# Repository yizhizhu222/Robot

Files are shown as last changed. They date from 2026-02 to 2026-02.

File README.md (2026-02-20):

# Vision-Rover: 基于 YOLOv8 的端侧视觉追踪机器人

> **“看见目标，精准出击”**
> 本项目是一个端到端的视觉追踪智能车解决方案。采用“上位机视觉+下位机控制”的标准机器人架构，结合轻量化 NCNN 框架与 FreeRTOS 实时系统，实现高帧率的目标检测与丝滑的差速底盘追踪。

---

## 免责声明 (Disclaimer)

**本项目为个人学习与极客折腾产物，核心目的是验证 YOLOv8 在 Orange Pi 端侧的部署可行性，以及 STM32 的底盘闭环控制逻辑。**

代码及硬件方案按“原样 (As-Is)”开源提供。由于嵌入式环境、硬件批次差异以及 Linux 权限的复杂性，本人不保证代码在任何第三方硬件上均能开箱即用，亦不提供环境配置的免费技术支持。

遇到报错的同学请自行发挥极客精神，善用搜索引擎与 AI 排查问题（提示：多留意串口权限与绝对路径）。祝折腾愉快！🍀

---

## 项目亮点
* **灵活定制**：支持在 Windows 端自定义训练 YOLOv8 模型，想追踪什么（人、小球、特定车辆）由你自己训练。
* **端侧极速推理**：利用 ncnn 框架在 Orange Pi Zero 3 上实现轻量化部署，榨干 ARM CPU 性能。
* **工业级底盘控制**：STM32F103C8T6 运行 FreeRTOS，结合双路编码器与 PID 闭环，实现精准的差速运动学调度。

---

## 硬件采购清单 (BOM)

如果你想从零复现本项目，需要准备以下核心硬件：

| 硬件分类 | 推荐型号/规格 | 作用说明 |
| :--- | :--- | :--- |
| **视觉大脑** | Orange Pi Zero 3 (香橙派) | 运行 Linux 系统与 NCNN 视觉推理算法 |
| **底盘小脑** | STM32F103C8T6 核心板 | 运行 FreeRTOS 实时控制电机与读取传感器 |
| **底盘结构** | 可参考项目内 PCB 扩展板 + 亚克力/金属车模 | 承载硬件与电路连接 |
| **执行机构** | 带有 AB 相霍尔编码器的直流减速电机 | 提供动力及速度反馈 |
| **视觉输入** | 普通 USB 摄像头 (免驱) | 采集环境图像 |
| **电源模块** | 12V 动力锂电池 + 5V 降压模块 (Buck) | 分别为电机和逻辑控制板供电 |
| **其他零配件** | JGB32-520 电机 *2 或 *4<br>85mm 实心轮胎 *2<br>BB 响 (用于航模电池测电)<br>双面胶 (实现 MVP 快速组装)<br>Type-C 数据线<br>T插公母头 (如使用航模电池)<br>TB6612 电机驱动模块<br>LM2596S DC 降压模块 | 组装必需的周边耗材与驱动件 |

---

## 硬件架构与供电接线 (Hardware & Wiring)

本项目的硬件供电逻辑经过专门设计，实现了大电流电机与精密逻辑主板的物理隔离供电，防止电压突变导致死机。

### 核心接线逻辑
1. **动力系统**：电池直接接入 PCB 底板，为 STM32 及电机驱动芯片提供原生大电流。
2. **逻辑降压**：电池通过红黑裸线接入降压模块，将电压降至稳定的 5V。
3. **视觉供电**：降压模块通过 Type-C 线连接 Orange Pi Zero 3，为其独立供电。
4. **通信连线**：Orange Pi 的 TX/RX 通过杜邦线连接至 PCB 对应的 RX/TX（波特率 `115200`）。

> **注：** 电机、编码器的具体连线以及 STM32 的详细引脚分配，请直接参考仓库中的 `PCB原理图` 与 `firmware/*.ioc` 工程配置文件。

---

## 软件架构与部署 (Software Architecture)

### 1. Windows PC 端：模型训练与转换
本项目不局限于特定目标，你可以自由训练模型：
1. 在 Windows 电脑上使用 PyTorch 训练自己的 YOLOv8 模型，导出 `.onnx`。
2. 使用 `onnx2ncnn` 工具，将模型转换为适用于端侧的 `.param`（网络结构）和 `.bin`（权重数据）文件。
3. 将生成的文件拷贝至香橙派的 `vision/model/` 目录下即可。

### 2. Orange Pi 端：视觉推理 (`vision/`)
负责捕捉图像并计算偏差下发指令。

```bash
# 1. 克隆项目 (直接在香橙派终端运行)
git clone [https://github.com/yizhizhu222/Robot.git](https://github.com/yizhizhu222/Robot.git)
cd Robot/vision

# 2. 编译视觉程序
mkdir build && cd build
cmake ..
make -j4

# 3. 运行追踪程序
./robot_eye

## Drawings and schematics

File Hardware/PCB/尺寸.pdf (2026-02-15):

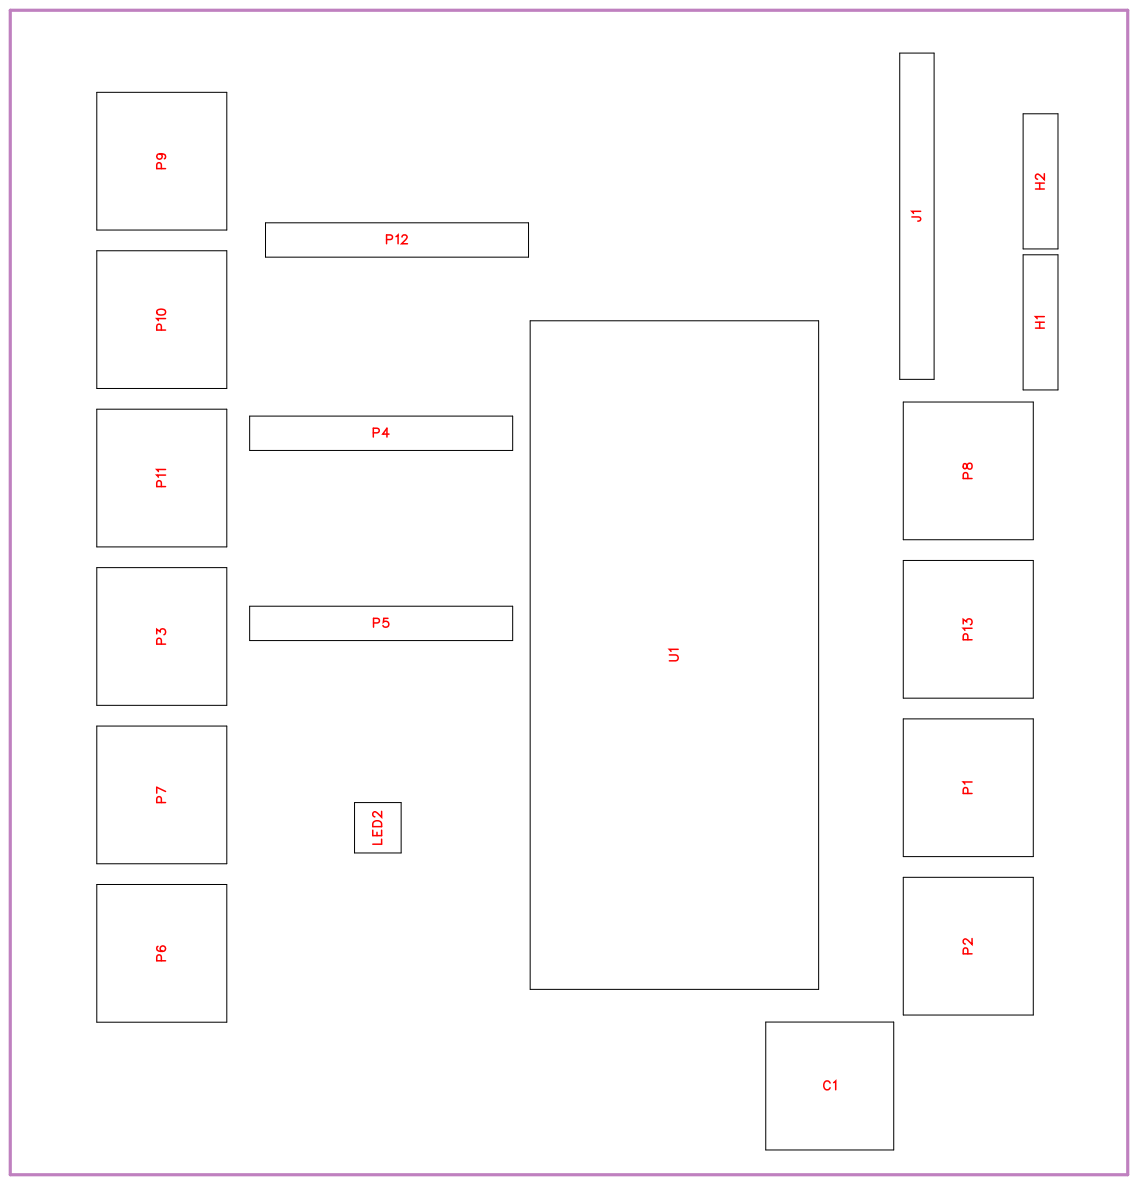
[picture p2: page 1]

No. | Quantity | Comment | Designator | Footprint | Value | Manufacturer Part | Manufacturer | Supplier Part | Supplier
1 | 1 | 470uF | C1 | CAP-TH_BD 10.0-P5.00-D 0.6-FD | 470uF | ERG35V470 M10X13 | JIERR(捷而 瑞) | C47344180 | LCSC
2 | 1 | 香橙派供电和 信息传输 | H1 | HDR-TH_4P-P2.54-V-F | | 香橙派供电和 信息传输 | BOOMELE( ) 博穆精密 | C2718488 | LCSC
3 | 1 | OLED 屏 | H2 | HDR-TH_4P-P2.54-V-F | | OLED 屏 | BOOMELE( ) 博穆精密 | C2718488 | LCSC
4 | 1 | 2.54-1*10P 母 | J1 | HDR-TH_10 P-P2.54-V-F | | 2.54-1*10P 母 | BOOMELE( 博穆精密 ) | C35445 | LCSC
5 | 1 | 3A4GUD | LED2 | LED-TH_BD 3.5-P2.54-R D-GREEN | | 3A4GUD | Guiguang lig ht(桂光光电 ) | C52034646 | LCSC
6 | 1 | 电池出口（进 降压模块） | P1 | CONN-TH_2 P-P5.00_WJ 500V-5.08-2 P | | 电池出口（进 降压模块） | KANGNEX( 康奈克斯电气 ) | C8465 | LCSC
7 | 1 | 电池入口 | P2 | CONN-TH_2 P-P5.00_WJ 500V-5.08-2 P | | 电池入口 | KANGNEX( 康奈克斯电气 ) | C8465 | LCSC
8 | 1 | 电机 2编码器 电源 | P3 | CONN-TH_2 P-P5.00_WJ 500V-5.08-2 P | | 电机 2编码器 电源 | KANGNEX( 康奈克斯电气 ) | C8465 | LCSC
9 | 3 | 2.54-1*8P 母 环保 | P4,P5,P12 | HDR-TH_8P-P2.54-V-F_2 | | 2.54-1*8P 母 环保 | BOOMELE( 博穆精密 ) | C27438 | LCSC
10 | 1 | 电机 2编码 | P6 | CONN-TH_2 P-P5.00_WJ 500V-5.08-2 P | | 2编码 电机 | KANGNEX( 康奈克斯电气 ) | C8465 | LCSC
11 | 1 | 电机 2电源 | P7 | CONN-TH_2 P-P5.00_WJ 500V-5.08-2 P | | 电机 2电源 | KANGNEX( 康奈克斯电气 ) | C8465 | LCSC
12 | 1 | 降压模块进口 | P8 | CONN-TH_2 P-P5.00_WJ 500V-5.08-2 P | | 降压模块进口 | KANGNEX( 康奈克斯电气 ) | C8465 | LCSC
13 | 1 | 电机 1编码 | P9 | CONN-TH_2 P-P5.00_WJ 500V-5.08-2 P | | 电机 1编码 | KANGNEX( 康奈克斯电气 ) | C8465 | LCSC
14 | 1 | 电机 1电源 | P10 | CONN-TH_2 P-P5.00_WJ 500V-5.08-2 P | | 电机 1电源 | KANGNEX( 康奈克斯电气 ) | C8465 | LCSC
15 | 1 | 电机 1编码器 电源 | P11 | CONN-TH_2 P-P5.00_WJ 500V-5.08-2 P | | 电机 1编码器 电源 | KANGNEX( 康奈克斯电气 ) | C8465 | LCSC

16 | 1 | 接入香橙派 | P13 | CONN-TH_2 P-P5.00_WJ 500V-5.08-2 P | 接入香橙派 | KANGNEX( 康奈克斯电气 ) | C8465 | LCSC
17 | 1 | LCKFB-DKX-STM32F103 C8T6 | U1 | CONN-TH_L 53.3-W22.9_ STM32F103 C8T6-CARD | LCKFB-DKX-STM32F103 C8T6 | 立创开发板 | C22396880 | LCSC

# GNDVCC

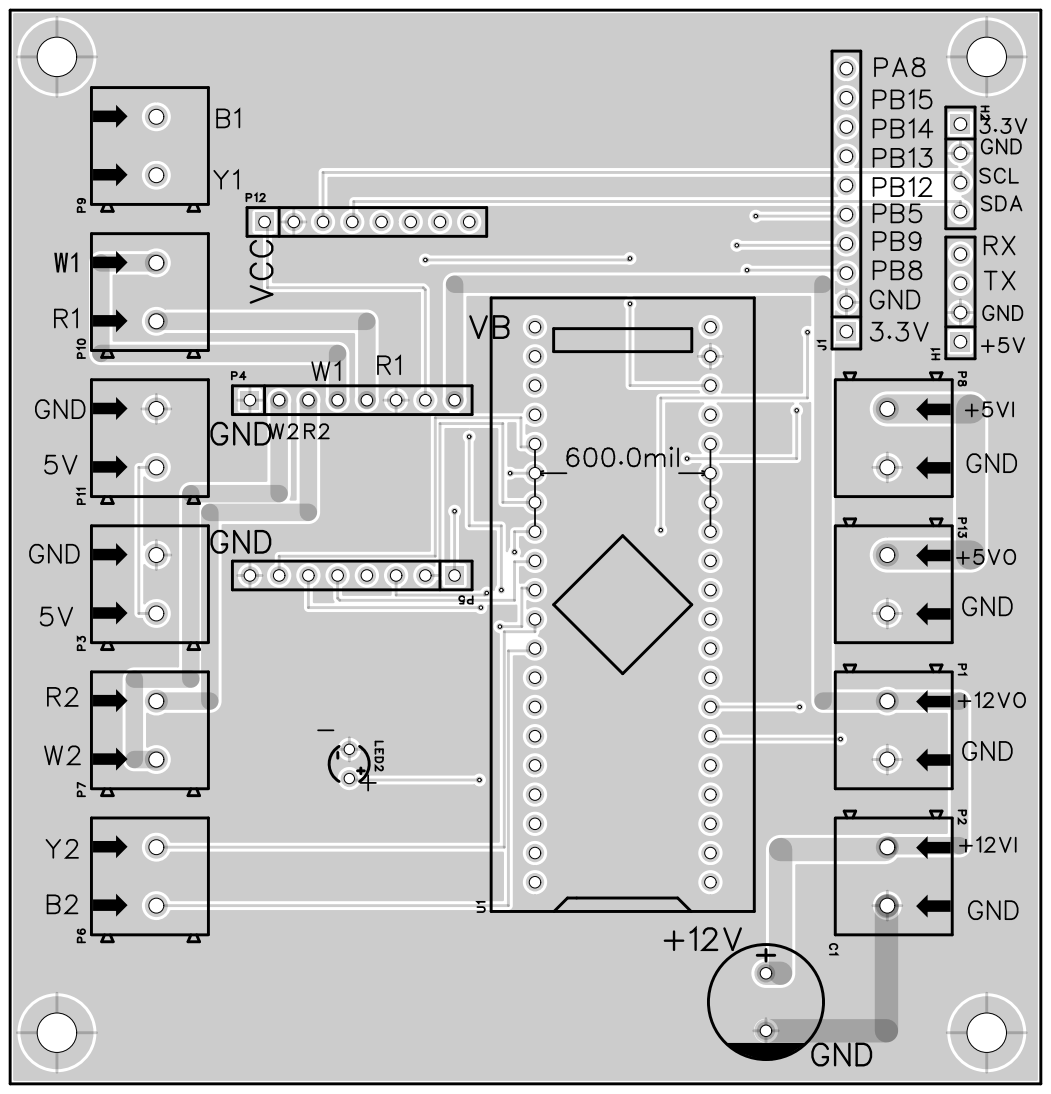
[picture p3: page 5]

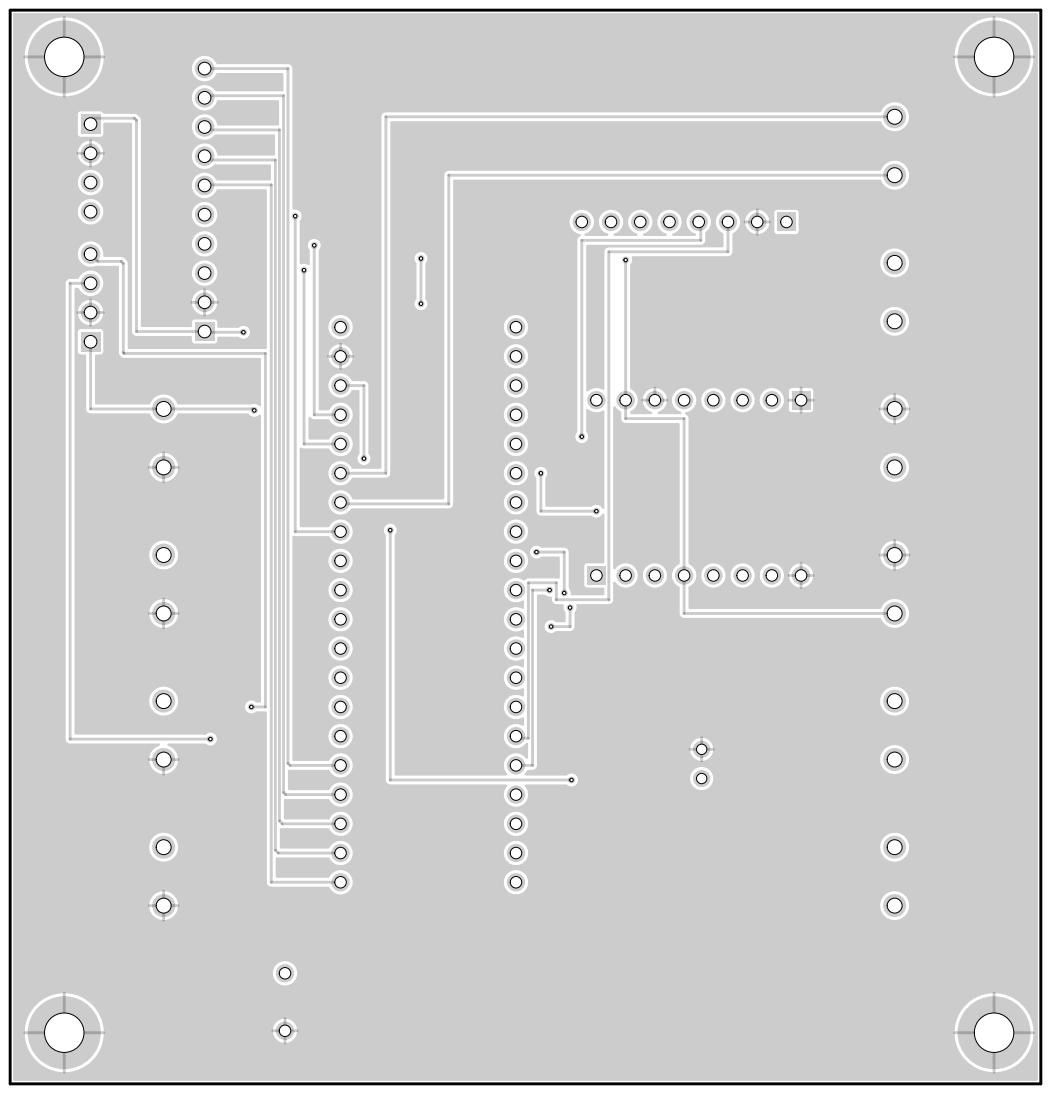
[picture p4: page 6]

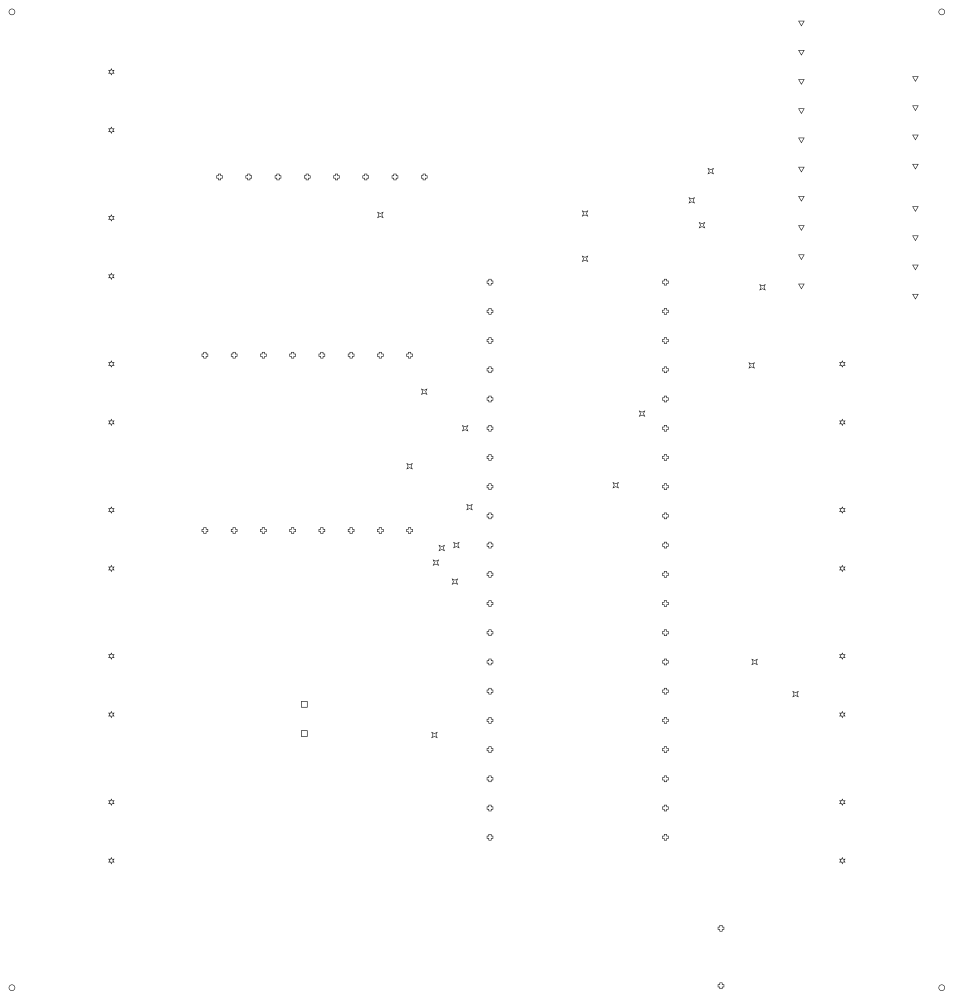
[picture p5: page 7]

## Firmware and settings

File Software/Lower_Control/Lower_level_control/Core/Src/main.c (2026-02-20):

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
/* Includes ------------------------------------------------------------------*/
#include "main.h"
#include "cmsis_os.h"

/* USER CODE BEGIN Includes */
#include <string.h>  // 必须加这个！解决 strstr 警告
#include <stdio.h>
#include <stdlib.h>
#include <protocol.h>
#include <chassis.h>
#include "pid.h"
#include "encoder.h"
#include "motor.h"
#include <math.h>
#include "mpu6050.h"
#include "kinematics.h"
#include "odometry.h"
/* USER CODE END Includes */

/* USER CODE BEGIN PM */
uint8_t rx_data;
/* USER CODE END PM */

I2C_HandleTypeDef hi2c2;

TIM_HandleTypeDef htim2;
TIM_HandleTypeDef htim3;
TIM_HandleTypeDef htim4;

UART_HandleTypeDef huart1;

/* Definitions for Task_Comm */
osThreadId_t Task_CommHandle;
const osThreadAttr_t Task_Comm_attributes = {
  .name = "Task_Comm",
  .stack_size = 256 * 4,
  .priority = (osPriority_t) osPriorityNormal,
};
/* Definitions for Task_Chassis */
osThreadId_t Task_ChassisHandle;
const osThreadAttr_t Task_Chassis_attributes = {
  .name = "Task_Chassis",
  .stack_size = 256 * 4,
  .priority = (osPriority_t) osPriorityHigh,
};
/* Definitions for Task_System */
osThreadId_t Task_SystemHandle;
const osThreadAttr_t Task_System_attributes = {
  .name = "Task_System",
  .stack_size = 256 * 4,
  .priority = (osPriority_t) osPriorityLow,
};
/* USER CODE BEGIN PV */
volatile float User_Target_Linear_X = 0.0f;  // 目标线速度
volatile float User_Target_Angular_Z = 0.0f; // 目标角速度

PID_TypeDef PID_MotorL; 
PID_TypeDef PID_MotorR;
/* USER CODE END PV */

void SystemClock_Config(void);
static void MX_GPIO_Init(void);
static void MX_TIM2_Init(void);
static void MX_USART1_UART_Init(void);
static void MX_TIM3_Init(void);
static void MX_TIM4_Init(void);
static void MX_I2C2_Init(void);
void Comm_Task_Entry(void *argument);
void Chassis_Task_Entry(void *argument);
void System_Task_Entry(void *argument);

/* USER CODE BEGIN 0 */
#define LED_PORT GPIOC
#define LED_PIN  GPIO_PIN_13 

void On_Receive_Velocity(float x, float z)
{
    HAL_GPIO_TogglePin(LED_PORT, LED_PIN);

    Protocol_Send_Odom(x, z); 
	//Chassis_Set_Velocity(x, z);
	User_Target_Linear_X = x;
    User_Target_Angular_Z = z;

}
/* USER CODE END 0 */

/**
  * @brief  The application entry point.
  * @retval int
  */
int main(void)
{

  /* MCU Configuration--------------------------------------------------------*/

  /* Reset of all peripherals, Initializes the Flash interface and the Systick. */
  HAL_Init();

  /* Configure the system clock */
  SystemClock_Config();

  /* Initialize all configured peripherals */
  MX_GPIO_Init();
  MX_TIM2_Init();
  MX_USART1_UART_Init();
  MX_TIM3_Init();
  MX_TIM4_Init();
  MX_I2C2_Init();
  /* USER CODE BEGIN 2 */
  
  // 启动 TIM2 的 Channel 1
  HAL_TIM_PWM_Start(&htim2, TIM_CHANNEL_1);
  // 开启中断接收，每收到 1 个字节，就进一次中断回调函数
  HAL_UART_Receive_IT(&huart1, &rx_data, 1);
  HAL_TIM_Base_Start_IT(&htim2);
  HAL_TIM_PWM_Start(&htim2, TIM_CHANNEL_1);
  HAL_TIM_PWM_Start(&htim2, TIM_CHANNEL_2);
  // 开启编码器计数
  Encoder_Init(); // 内部开启了 TIM3, TIM4
  // 开启 PWM (TIM2/TIM1)
  Motor_Init(); // 内部调用了 HAL_TIM_PWM_Start(&htim1...)
  // 开启串口接收
  HAL_UART_Receive_IT(&huart1, &rx_data, 1);
  MPU_Init();
  MPU_Calibrate();
  /* USER CODE END 2 */

  /* Init scheduler */
  osKernelInitialize();

  /* USER CODE BEGIN RTOS_MUTEX */
  /* add mutexes, ... */
  /* USER CODE END RTOS_MUTEX */

  /* USER CODE BEGIN RTOS_SEMAPHORES */
  /* add semaphores, ... */
  /* USER CODE END RTOS_SEMAPHORES */

  /* USER CODE BEGIN RTOS_TIMERS */
  /* start timers, add new ones, ... */
  /* USER CODE END RTOS_TIMERS */

  /* USER CODE BEGIN RTOS_QUEUES */
  /* add queues, ... */
  /* USER CODE END RTOS_QUEUES */

  /* Create the thread(s) */
  /* creation of Task_Comm */
  Task_CommHandle = osThreadNew(Comm_Task_Entry, NULL, &Task_Comm_attributes);

  /* creation of Task_Chassis */
  Task_ChassisHandle = osThreadNew(Chassis_Task_Entry, NULL, &Task_Chassis_attributes);

  /* creation of Task_System */
  Task_SystemHandle = osThreadNew(System_Task_Entry, NULL, &Task_System_attributes);

  /* USER CODE BEGIN RTOS_THREADS */
  /* add threads, ... */
  /* USER CODE END RTOS_THREADS */

  /* USER CODE BEGIN RTOS_EVENTS */
  /* add events, ... */
  /* USER CODE END RTOS_EVENTS */

  /* Start scheduler */
  osKernelStart();

  /* We should never get here as control is now taken by the scheduler */

  /* Infinite loop */
  /* USER CODE BEGIN WHILE */
  while (1)
  {
    /* USER CODE END WHILE */

    /* USER CODE BEGIN 3 */
  }
  /* USER CODE END 3 */
}

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
/* USER CODE BEGIN 4 */
// 串口接收中断回调函数
// 串口接收中断回调函数
void HAL_UART_RxCpltCallback(UART_HandleTypeDef *huart)
{
    // 判断是不是 USART1 产生的中断
    if (huart->Instance == USART1)
    {
        // 【核心修改】
        // 不需要等 \n，不需要存数组，直接把这个字节喂给解码器！
        Protocol_Decode(rx_data);

        // 重新开启中断，准备接收下一个字节
        HAL_UART_Receive_IT(&huart1, &rx_data, 1);
    }
}
/* USER CODE END 4 */

/* USER CODE BEGIN Header_Comm_Task_Entry */
/**
  * @brief  Function implementing the Task_Comm thread.
  * @param  argument: Not used
  * @retval None
  */
/* USER CODE END Header_Comm_Task_Entry */
void Comm_Task_Entry(void *argument)
{
  /* USER CODE BEGIN 5 */
	
  /* Infinite loop */
  for(;;)
  {
        osDelay(1);
  }
  /* USER CODE END 5 */
}

/* USER CODE BEGIN Header_Chassis_Task_Entry */
/**
* @brief Function implementing the Task_Chassis thread.
* @param argument: Not used
* @retval None
*/
/* USER CODE END Header_Chassis_Task_Entry */
void Chassis_Task_Entry(void *argument)
{
  /* USER CODE BEGIN Chassis_Task_Entry */
	Odometry_Init();
  Chassis_Init();
  Encoder_Init();
  
  // 保持你刚才测试成功的强力参数！千万别改回去了！
  PID_Init(&PID_MotorL, 80.0f, 0.5f, 0.0f, 7199.0f, 4000.0f);
  PID_Init(&PID_MotorR, 80.0f, 0.5f, 0.0f, 7199.0f, 4000.0f);

  Kinematics_Motor_Speed_t target_speed_mps;
  Kinematics_Motor_Pulse_t target_pulse;
  int min_startup_pwm = 1500; // 保持这个低保值

  for(;;)
  {
    // 1. 获取真实指令
    float test_linear_x = User_Target_Linear_X; 
    float test_angular_z = User_Target_Angular_Z;

    // 2. 解算
    target_speed_mps = Kinematics_Inverse(test_linear_x, test_angular_z);
    target_pulse = Kinematics_SpeedToPulse(target_speed_mps, 0.05f);

    // 3. 反馈与PID
    float current_pulse_L = (float)Read_Encoder_Motor1();
    float current_pulse_R = (float)Read_Encoder_Motor2();
    float pwm_L = PID_Compute(&PID_MotorL, target_pulse.left_ticks, current_pulse_L);
    float pwm_R = PID_Compute(&PID_MotorR, target_pulse.right_ticks, current_pulse_R);

    // 4. 安全停车 (如果目标是0，强制关断)
    if (fabs(test_linear_x) < 0.01f && fabs(test_angular_z) < 0.01f) {
        pwm_L = 0;
        pwm_R = 0;
        PID_MotorL.Sum_Error = 0; // 清积分
        PID_MotorR.Sum_Error = 0;
    }
    else {
        // 5. 起步低保 (只有在目标不为0时才给)
        // 左轮
        if (pwm_L > 0 && pwm_L < min_startup_pwm) pwm_L = min_startup_pwm;
        else if (pwm_L < 0 && pwm_L > -min_startup_pwm) pwm_L = -min_startup_pwm;
        // 右轮
        if (pwm_R > 0 && pwm_R < min_startup_pwm) pwm_R = min_startup_pwm;
        else if (pwm_R < 0 && pwm_R > -min_startup_pwm) pwm_R = -min_startup_pwm;
    }

    // 6. 输出
    Motor1_SetSpeed((int)pwm_L);
    Motor2_SetSpeed((int)pwm_R);

    osDelay(50);
  }
  /* USER CODE END Chassis_Task_Entry */
}

/* USER CODE BEGIN Header_System_Task_Entry */
/**
* @brief Function implementing the Task_System thread.
* @param argument: Not used
* @retval None
*/
/* USER CODE END Header_System_Task_Entry */
void System_Task_Entry(void *argument)
{
  /* USER CODE BEGIN System_Task_Entry */
  /* Infinite loop */
  for(;;)
  {
    osDelay(1);
  }
  /* USER CODE END System_Task_Entry */
}

/**
  * @brief  Period elapsed callback in non blocking mode
  * @note   This function is called  when TIM1 interrupt took place, inside
  * HAL_TIM_IRQHandler(). It makes a direct call to HAL_IncTick() to increment
  * a global variable "uwTick" used as application time base.
  * @param  htim : TIM handle
  * @retval None
  */
void HAL_TIM_PeriodElapsedCallback(TIM_HandleTypeDef *htim)
{
  if (htim->Instance == TIM1)
  {
    HAL_IncTick();
  }
}

/**
  * @brief  This function is executed in case of error occurrence.
  * @retval None
  */
void Error_Handler(void)
{
  /* USER CODE BEGIN Error_Handler_Debug */
  /* User can add his own implementation to report the HAL error return state */
  __disable_irq();
  while (1)
  {
  }
  /* USER CODE END Error_Handler_Debug */
}
#ifdef USE_FULL_ASSERT
/**
  * @brief  Reports the name of the source file and the source line number
  *         where the assert_param error has occurred.
  * @param  file: pointer to the source file name
  * @param  line: assert_param error line source number
  * @retval None
  */
void assert_failed(uint8_t *file, uint32_t line)
{
  /* USER CODE BEGIN 6 */
  /* User can add his own implementation to report the file name and line number,
     ex: printf("Wrong parameters value: file %s on line %d\r\n", file, line) */
  /* USER CODE END 6 */
}
#endif /* USE_FULL_ASSERT */

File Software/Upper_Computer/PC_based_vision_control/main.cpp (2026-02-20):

#include <opencv2/opencv.hpp>
#include <stdio.h>
#include <sys/time.h>
#include <fcntl.h>
#include <unistd.h>
#include <termios.h>
#include <string.h> 
#include "yolo.h"

// ================= 核心参数调优区域 (新手最常改这里) =================
#define CENTER_X        160.0f    // 画面中心点 (320宽度的一半)
#define KP_TURN         0.01f     // 【转向灵敏度】数值越大，转弯越猛
#define MAX_TURN_SPEED  1.0f      // 【转速上限】防止机器人转得太快把自己甩飞
#define FORWARD_SPEED   0.2f      // 【前进速度】单位通常是 m/s
#define CONFIDENCE_MIN  0.45f     // 【置信度门槛】低于这个分数的物体会被忽略

// ================= 串口通信 (下位机协议) =================
/**
 * @brief 打开并配置串口 (与单片机通信)
 */
int open_serial(const char *device) {
    int fd = open(device, O_RDWR | O_NOCTTY | O_NDELAY);
    if (fd == -1) { perror("错误：无法打开串口"); return -1; }
    
    struct termios options;
    tcgetattr(fd, &options);
    cfsetispeed(&options, B115200); // 波特率 115200
    cfsetospeed(&options, B115200);
    options.c_cflag |= (CLOCAL | CREAD); // 忽略控制线，开启读取
    options.c_cflag &= ~PARENB;          // 无校验
    options.c_cflag &= ~CSTOPB;          // 1位停止位
    options.c_cflag &= ~CSIZE;
    options.c_cflag |= CS8;              // 8位数据
    
    // 原始模式 (Raw Mode)，不进行回显和换行处理
    options.c_lflag &= ~(ICANON | ECHO | ECHOE | ISIG); 
    options.c_oflag &= ~OPOST;
    tcsetattr(fd, TCSANOW, &options);
    return fd;
}

// 定义发送给机器人的数据结构
struct Velocity_Payload { 
    float linear_x;  // 线速度 (前后)
    float angular_z; // 角速度 (左右转向)
};

/**
 * @brief 按照通讯协议打包并发送速度指令
 */
void send_velocity_command(int fd, float linear_x, float angular_z) {
    uint8_t tx_buf[32]; 
    int idx = 0;
    Velocity_Payload payload = {linear_x, angular_z};
    uint8_t len = sizeof(payload);

    // 填充协议头
    tx_buf[idx++] = 0xAA; // 帧头 1
    tx_buf[idx++] = 0x55; // 帧头 2
    tx_buf[idx++] = 0x10; // 命令 ID: 设置速度
    tx_buf[idx++] = len;  // 数据长度
    
    // 拷贝速度数据
    memcpy(&tx_buf[idx], &payload, len);
    idx += len;

    // 计算校验和 (防止数据传错)
    uint8_t checksum = 0x10 + len;
    uint8_t *pData = (uint8_t*)&payload;
    for (int i = 0; i < len; i++) checksum += pData[i];
    tx_buf[idx++] = checksum;

    write(fd, tx_buf, idx);
}

// ================= 主循环 (大脑运行逻辑) =================
int main() {
    // 1. 初始化串口
    int serial_fd = open_serial("/dev/ttyAS5");
    if (serial_fd != -1) printf("✅ 串口已连接\n");

    // 2. 初始化摄像头 (设置分辨率为 320x240)
    cv::VideoCapture cap(0);
    cap.set(cv::CAP_PROP_FRAME_WIDTH, 320);
    cap.set(cv::CAP_PROP_FRAME_HEIGHT, 240);
    if (!cap.isOpened()) { printf("❌ 无法打开摄像头\n"); return -1; }

    // 3. 加载 YOLO 模型
    Yolo yolo;
    if (yolo.load("/home/orangepi/my_robot/model/yolov8", 320) != 0) return -1;
    
    cv::Mat frame;
    std::vector<Object> objects;
    
    // --- 状态变量 (用于平滑控制) ---
    int lost_target_counter = 0; // 丢失计数器：防止目标闪烁导致车乱跳
    float last_v = 0.0f;
    float last_w = 0.0f;

    while (true) {
        cap >> frame;
        if (frame.empty()) break;

        objects.clear();
        yolo.detect(frame, objects); // 执行目标检测

        float v_x = 0.0f; // 本帧线速度
        float w_z = 0.0f; // 本帧角速度
        bool valid_target_found = false;

        // 策略 A：如果有看到物体
        if (!objects.empty()) {
            const auto& obj = objects[0]; // 只追踪看到的第一个物体
            
            if (obj.prob > CONFIDENCE_MIN) {
                valid_target_found = true;
                lost_target_counter = 0; // 看到东西了，重置丢失计时

                // --- 计算偏离距离 ---
                float cx = obj.rect.x + obj.rect.width / 2.0f; // 物体中心 X
                float error = cx - CENTER_X; // 物体相对于屏幕中心的偏离量

                // 只有偏离超过 20 像素才转向，防止原地细微抖动 (死区逻辑)
                if (abs(error) < 20.0f) error = 0.0f;

                // --- 比例控制 (P 控制) ---
                // 物体在左 (error<0) -> 需要左转 (w_z 为正)
                // 物体在右 (error>0) -> 需要右转 (w_z 为负)
                w_z = -error * KP_TURN; 

                // 限速保护：不要超过电机最大负荷
                if (w_z > MAX_TURN_SPEED) w_z = MAX_TURN_SPEED;
                if (w_z < -MAX_TURN_SPEED) w_z = -MAX_TURN_SPEED;

                v_x = FORWARD_SPEED; // 看到目标就匀速前进
                
                // 记录状态，用于丢失后的“惯性”维持
                last_v = v_x;
                last_w = w_z;

                printf("🎯 [追踪中] 偏差: %.1f | 转向速度: %.3f\n", error, w_z);
            }
        }

        // 策略 B：如果目标丢了 (防抖处理)
        if (!valid_target_found) {
            lost_target_counter++;
            
            // 如果丢失时间很短 (少于 5 帧，约 0.2 秒)
            // 机器人会按照上一帧的指令继续跑，避免因为检测断开而急刹车
            if (lost_target_counter < 5) {
                v_x = last_v;
                w_z = last_w;
                printf("⚠️ [目标丢失] 维持惯性... (%d/5)\n", lost_target_counter);
            } else {
                // 彻底丢了，安全停车
                v_x = 0.0f;
                w_z = 0.0f;
            }
        }

        // 4. 发送指令到电机控制板
        if (serial_fd != -1) {
            send_velocity_command(serial_fd, v_x, w_z);
        }
    }

    if (serial_fd != -1) close(serial_fd);
    return 0;
}

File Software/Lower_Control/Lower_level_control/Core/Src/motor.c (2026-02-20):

#include "motor.h"
#include "stm32f1xx_hal.h"
#include "math.h"

extern TIM_HandleTypeDef htim2; 

// 设置电机1 (PB6/7那边的电机) 的PWM和方向
// pwm_val 范围: -Output_Limit 到 +Output_Limit
void Motor1_SetSpeed(int pwm_val) {
    // 1. 处理方向
    if (pwm_val >= 0) {
        HAL_GPIO_WritePin(GPIOA, GPIO_PIN_3, GPIO_PIN_SET);   // AIN1 (示例)
        HAL_GPIO_WritePin(GPIOA, GPIO_PIN_2, GPIO_PIN_RESET); // AIN2 (示例)
    } else {
        HAL_GPIO_WritePin(GPIOA, GPIO_PIN_3, GPIO_PIN_RESET);
        HAL_GPIO_WritePin(GPIOA, GPIO_PIN_2, GPIO_PIN_SET);
        pwm_val = -pwm_val; // 取绝对值作为占空比
    }
    // 2. 输出PWM
    __HAL_TIM_SET_COMPARE(&htim2, TIM_CHANNEL_1, pwm_val); 
}

// 设置电机2 (PA6/7那边的电机)
void Motor2_SetSpeed(int pwm_val) {
    if (pwm_val >= 0) {
        HAL_GPIO_WritePin(GPIOA, GPIO_PIN_4, GPIO_PIN_SET);   // BIN1 (示例)
        HAL_GPIO_WritePin(GPIOA, GPIO_PIN_5, GPIO_PIN_RESET); // BIN2 (示例)
    } else {
        HAL_GPIO_WritePin(GPIOA, GPIO_PIN_4, GPIO_PIN_RESET);
        HAL_GPIO_WritePin(GPIOA, GPIO_PIN_5, GPIO_PIN_SET);
        pwm_val = -pwm_val;
    }
    __HAL_TIM_SET_COMPARE(&htim2, TIM_CHANNEL_2, pwm_val);
}
void Motor_Init(void) {
    // 1. 开启 PWM 输出
    // 注意：如果你用的是 TIM2 的通道1和通道2，代码如下：
    HAL_TIM_PWM_Start(&htim2, TIM_CHANNEL_1);
    HAL_TIM_PWM_Start(&htim2, TIM_CHANNEL_2);
    
    // 2. 初始化方向引脚 (可选，因为GPIO Init已经在main里做过了)
    // 这里为了保险，可以先把所有方向引脚拉低（停止状态）
    HAL_GPIO_WritePin(MOTOR1_IN1_PORT, MOTOR1_IN1_PIN, GPIO_PIN_RESET);
    HAL_GPIO_WritePin(MOTOR1_IN2_PORT, MOTOR1_IN2_PIN, GPIO_PIN_RESET);
    HAL_GPIO_WritePin(MOTOR2_IN1_PORT, MOTOR2_IN1_PIN, GPIO_PIN_RESET);
    HAL_GPIO_WritePin(MOTOR2_IN2_PORT, MOTOR2_IN2_PIN, GPIO_PIN_RESET);
}
// 参数：motor_id(1=左, 2=右), pid_output(PID算出来的结果)
void Motor_Set_Output(int motor_id, float pid_output) 
{
    // 1. 获取 PWM 的绝对值 (负数变正数，因为占空比不能是负的)
    int pwm_val = (int)fabs(pid_output);

    // 2. 这里的引脚请根据你实际接线修改！！！
    // 假设：IN1/IN2 是左轮，IN3/IN4 是右轮
    if (pid_output >= 0) {
        // --- 正转逻辑 ---
        if(motor_id == 1) { // 左轮正转
            HAL_GPIO_WritePin(GPIOA, GPIO_PIN_3, GPIO_PIN_SET);   // 改你的引脚
            HAL_GPIO_WritePin(GPIOA, GPIO_PIN_2, GPIO_PIN_RESET); 
        } else {            // 右轮正转
            HAL_GPIO_WritePin(GPIOA, GPIO_PIN_4, GPIO_PIN_SET);   // 改你的引脚
            HAL_GPIO_WritePin(GPIOA, GPIO_PIN_5, GPIO_PIN_RESET);
        }
    } else {
        // --- 反转逻辑 (PID算出来是负数) ---
        if(motor_id == 1) { // 左轮反转
            HAL_GPIO_WritePin(GPIOA, GPIO_PIN_3, GPIO_PIN_RESET); // 改你的引脚
            HAL_GPIO_WritePin(GPIOA, GPIO_PIN_2, GPIO_PIN_SET);
        } else {            // 右轮反转
            HAL_GPIO_WritePin(GPIOA, GPIO_PIN_4, GPIO_PIN_RESET); // 改你的引脚
            HAL_GPIO_WritePin(GPIOA, GPIO_PIN_5, GPIO_PIN_SET);
        }
    }

    // 3. 发送 PWM 给定时器 (假设电机用 TIM1 的 CH1 和 CH4)
    if(motor_id == 1) {
        __HAL_TIM_SET_COMPARE(&htim2, TIM_CHANNEL_1, pwm_val);
    } else {
        __HAL_TIM_SET_COMPARE(&htim2, TIM_CHANNEL_2, pwm_val);
    }
}

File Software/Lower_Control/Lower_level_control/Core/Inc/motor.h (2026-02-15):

#ifndef __MOTOR_H__
#define __MOTOR_H__

#include "main.h"

// ================= 引脚配置区 (请根据你的实际连线修改) =================

// 电机1 (PB6/PB7那边) 的控制引脚 (TB6612 AIN1/AIN2)
#define MOTOR1_IN1_PIN   GPIO_PIN_4   // 举例：PA4
#define MOTOR1_IN1_PORT  GPIOA
#define MOTOR1_IN2_PIN   GPIO_PIN_5   // 举例：PA5
#define MOTOR1_IN2_PORT  GPIOA

// 电机2 (PA6/PA7那边) 的控制引脚 (TB6612 BIN1/BIN2)
#define MOTOR2_IN1_PIN   GPIO_PIN_2   // 举例：PA2
#define MOTOR2_IN2_PIN   GPIO_PIN_3   // 举例：PA3
#define MOTOR2_IN2_PORT  GPIOA
#define MOTOR2_IN1_PORT  GPIOA

// ===================================================================

// 函数声明
void Motor_Init(void);               // 电机初始化（开启PWM等）
void Motor1_SetSpeed(int pwm_val);   // 设置电机1速度
void Motor2_SetSpeed(int pwm_val);   // 设置电机2速度

#endif

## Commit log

2026-02-15 首次提交：初始化机器人小车项目结构
    [Drill_PTH_Through.DRL, Drill_PTH_Through_Via.DRL, Gerber_BoardOutlineLayer.GKO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]
2026-02-20 chore: 重新梳理项目结构，清理编译缓存
2026-02-20 fix: 移除子模块并修复灰色文件夹无法打开的问题
    [yolov8.param]
2026-02-20 fix: 更新stm32代码

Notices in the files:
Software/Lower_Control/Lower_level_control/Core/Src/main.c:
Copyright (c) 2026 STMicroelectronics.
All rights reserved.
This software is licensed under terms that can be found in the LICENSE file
